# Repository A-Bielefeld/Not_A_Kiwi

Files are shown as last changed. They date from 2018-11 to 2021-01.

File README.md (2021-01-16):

# Not_A_Kiwi

This is an old begineer project, this electronics shouldn't be replicated or used for may reasons. It stands here as an archive to remind myself of how my very first project turned out!

<p align="center">
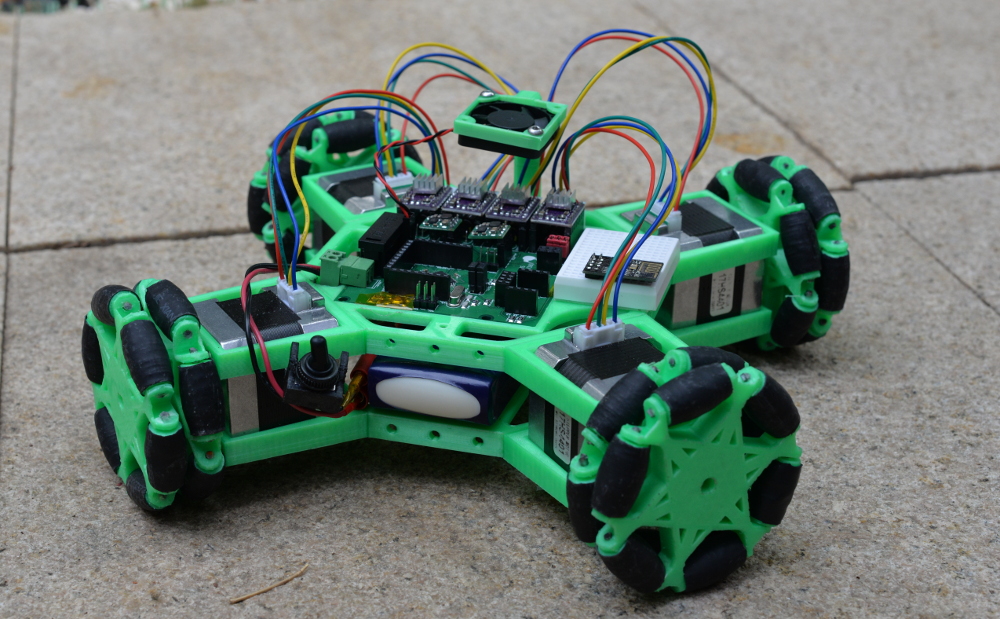
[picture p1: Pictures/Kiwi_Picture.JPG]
kiwi_robot

</p>

Not A Kiwi is an Open-Source, fully 3D printed modular robot controlled by a custom PCB. Its aims are to be an educational platform for engineering students and an entry in the 2019 Coupe de France de Robotique for the Robotics Assocations of Télécom Physique Strasbourg as a secondary robot.

This robot is meant for anyone seeking to have a fun and looking for an open robotics plateform to learn and expand on. The only tool needed to build one is a 3D printer, as the PCB can be bought online or provided by me (soldered or not).

## Features
- Based on a standard ATMega32, the board is arduino compatible (tested).
- Many headers and an integrated breadboard to test out new ideas and add sensors.
- Very easy to print, no complex parts.
- Modular 3D printed structure makes it easy to add any kind of sensor or effector.
- ESP01 socket (UART or I2C communication with the AVR) for IoT applications.

## Hardware
The hardware is the most developped part of this project as the code is still being written.

### BOM
- 4 Nema17 stepper motors (38mm)
- 4 DRV8825 stepper motor driver carriers (or A4988-Pinout-Compatible)
- 5V Pololu Regulator (D24V5F5, but I intend to replace them with a simpler/cheaper solution)
- 3.3V Pololu regulator (D24V5F3)
- ESP01 (not required)
- 12V LiPo battery (but any 12V to 36V battery will work fine)
- Not A Kiwi Board (Detailed below)
- Small Breadboard
- 30mm 0.15A fan
- 3D printed structure

#### Not A Kiwi Board

<p align="center">
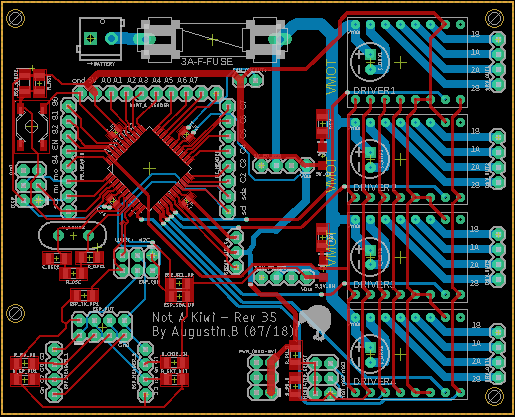
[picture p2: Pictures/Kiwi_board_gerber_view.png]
PCB_gerber_view

</p>

The board is a simple Atmega32 based board that includes 4 stepper motor driver carriers sockets as well as support for an ESP01 chip, communicating over either UART or I2C depending on a choice of jumpers. The BOM is rather small, as the board is meant to be programmed through ICSP. It is easily possible to send the BOM and Gerber files to a PCB production service to obtain one, although I can also provide fully soldered and tested ones for a fee (Europe only).

#### PCB BOM
The board uses a majority of SMD components, all 1206 except the AVR smoothing capacitor and a zener diode.

Most of these components can be soldered by hand, although it is advised to use solder paste and a reflow oven (a simple and inexpensive toaster oven is enough for this purpose).

Full BOM files will be provided in the repository, in a format compatible with most PCB manufacturers. 
An article explaining the choices behind the parts, and possible alternatives will be available on the wiki.

#### 3D printed structure

  The robot uses a simple 3D printed structure composed of 12 parts, it takes approximately 12 hours to print, not counting in the 3D printed omniwheels, but it would be much better to use bought ones, albeit more expensive (3D printed wheels have a negligeable cost, but perform more poorly, several design will be tested and offered here).
  
  The CAD files provided are Fusion 360 parametric files and therefore should also be compatible with Autodesk Inventor and SolidWorks (tested). If you just wish to print the robot, .STL files are also provided. The Kit also uses M3 screws and nuts, it is very quick and easy to assemble (less than an hour).
  
  <p align="center">
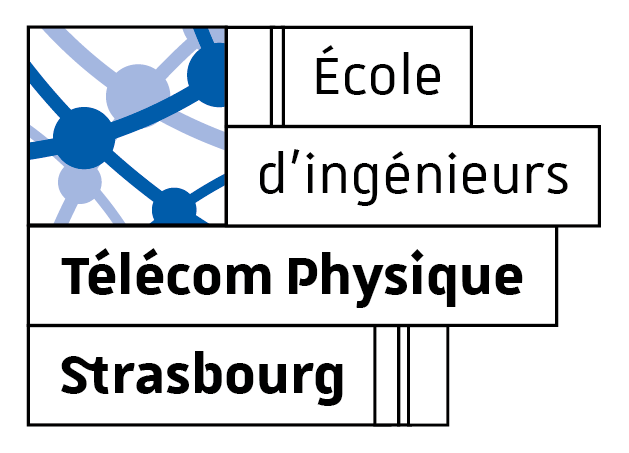
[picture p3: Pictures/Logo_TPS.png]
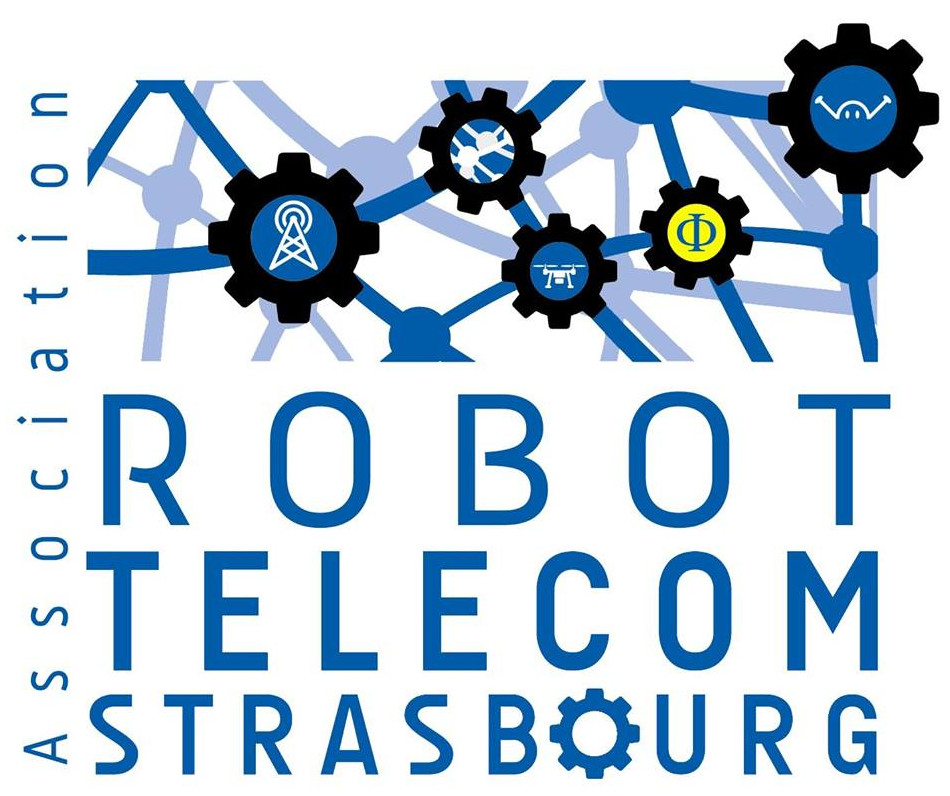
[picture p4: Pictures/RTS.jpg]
</p>

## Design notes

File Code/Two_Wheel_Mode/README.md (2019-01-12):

# Two wheeled driving mode

<p align="center">
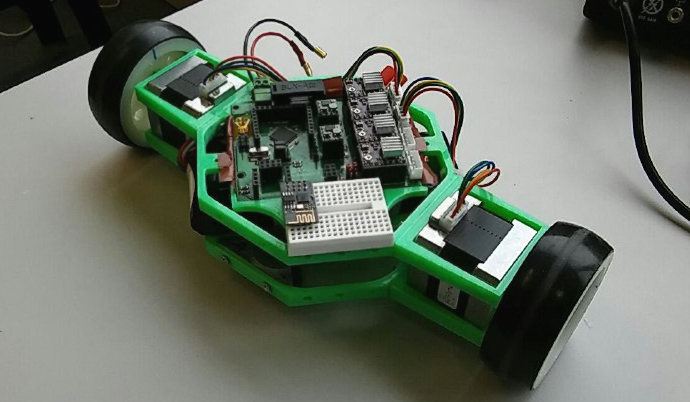
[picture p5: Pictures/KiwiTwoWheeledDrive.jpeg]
kiwi_robot in two wheeled mode

</p>

You can alter the structure by removing two motors bays and adding wheels and rollers on the bottom you can use this plateform in a simpler driving mode.
Polar movement code is provided here, for now it's a simple implementation providing rotational, and linear moves, along with two simple planning functions.

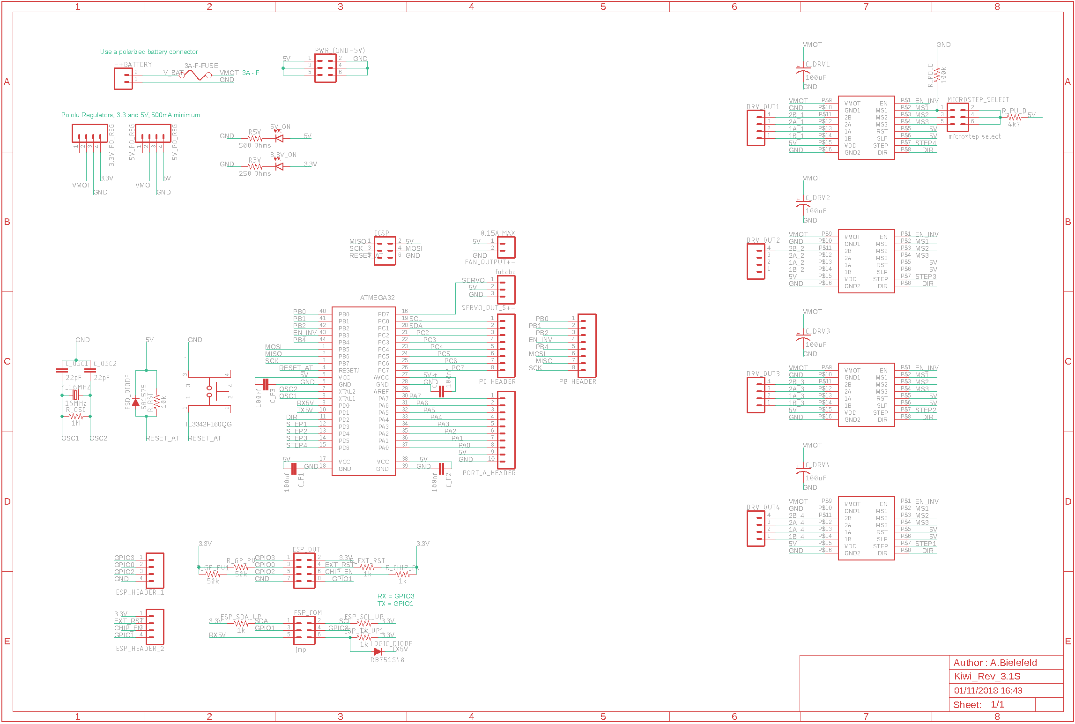
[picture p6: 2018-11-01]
Kiwi_Board/NAK_Board_Schematic_R3.1S.png

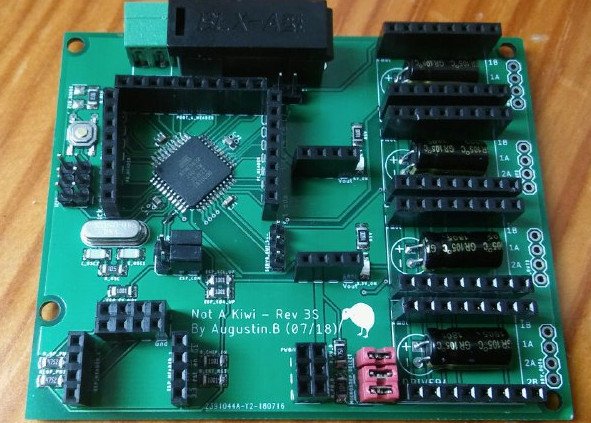
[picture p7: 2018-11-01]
Pictures/Kiwi_board_image.JPG

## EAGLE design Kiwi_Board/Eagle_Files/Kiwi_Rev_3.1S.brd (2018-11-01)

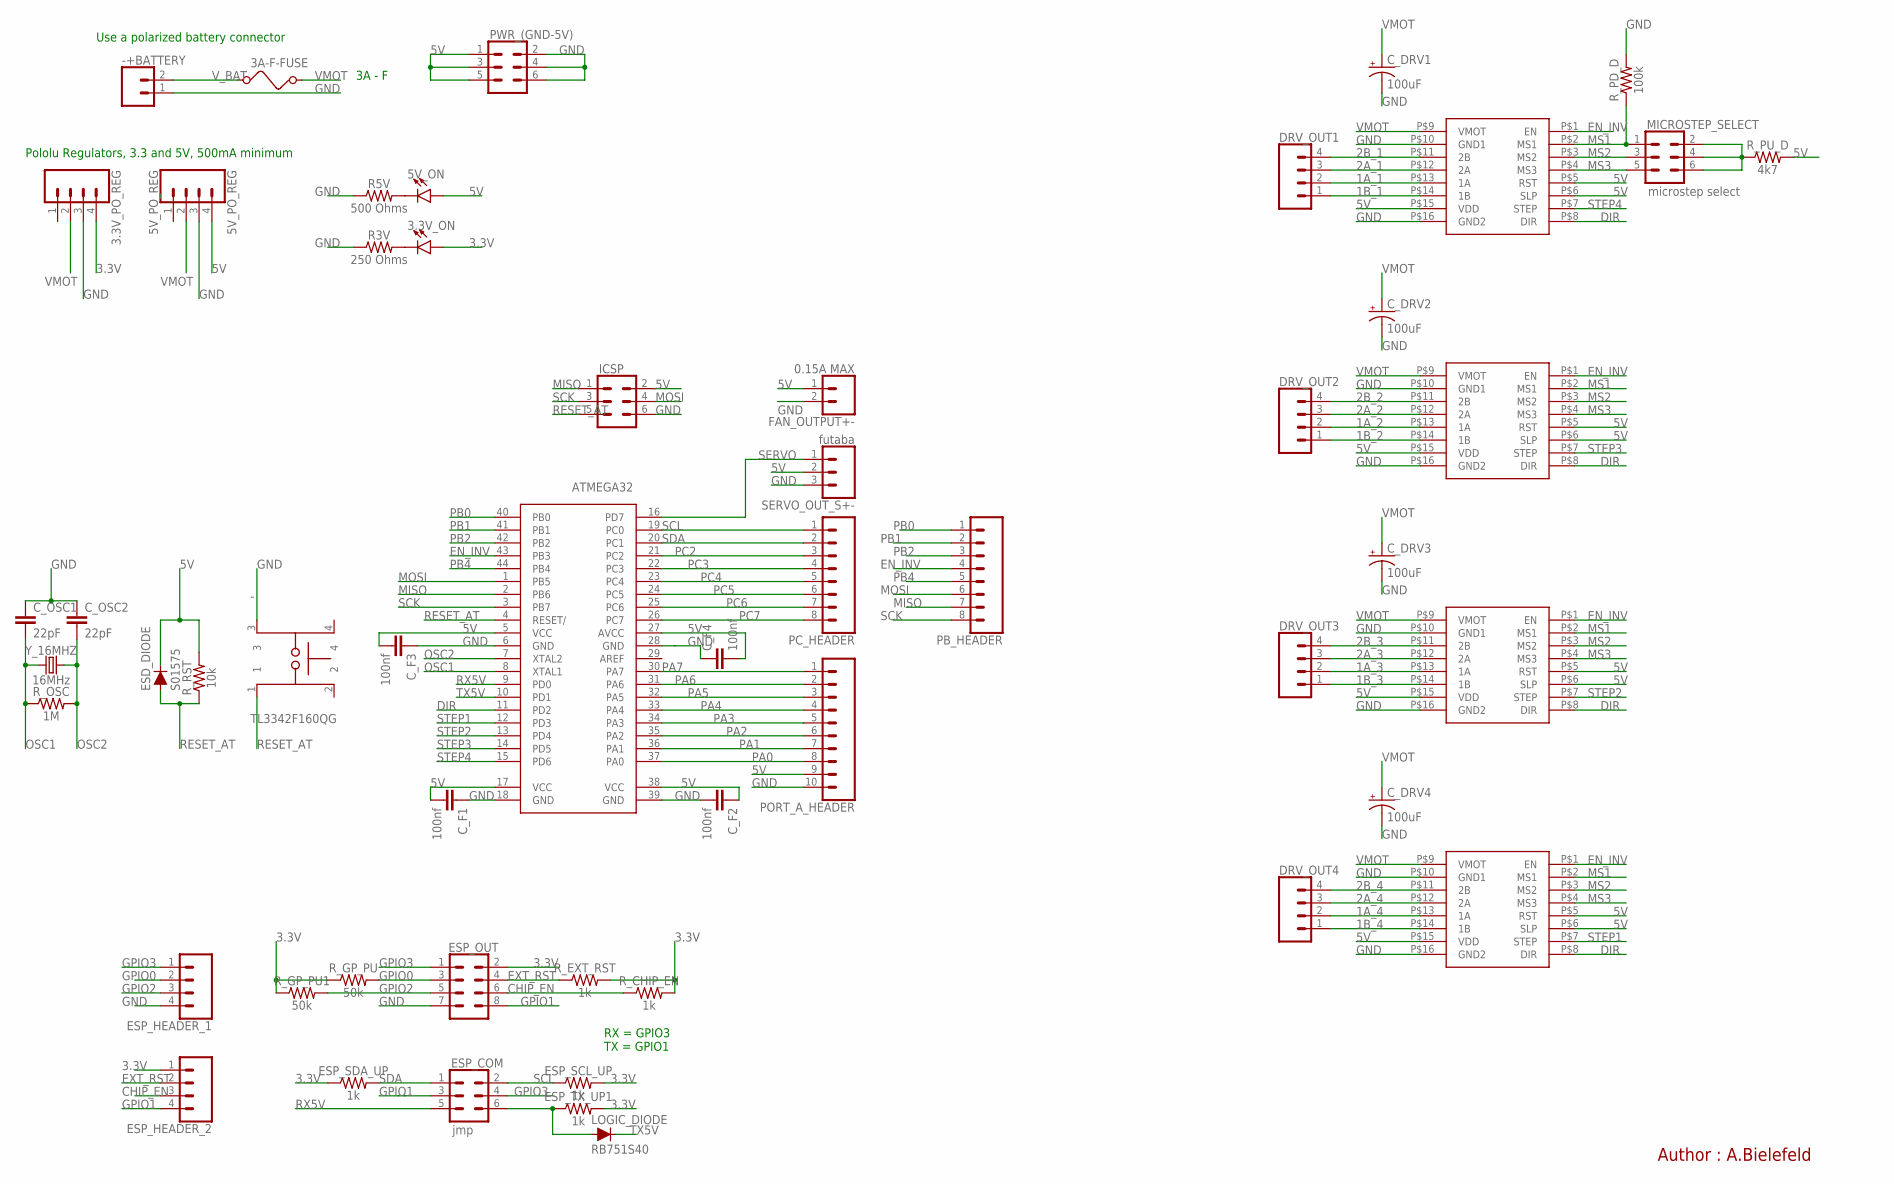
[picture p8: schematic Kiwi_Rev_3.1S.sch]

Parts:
3.3V_ON, 5V_ON: LED1206; LED-1206
3.3V_PO_REG: CONN_04; 1X04
3A-F-FUSE: FUSE
5V_PO_REG: 5V_PO_REG; 1X04
-: TL3342F160QG; SW_TL3342F160QG
-+BATTERY: CONN_023.5MM; SCREWTERMINAL-3.5MM-2
ATMEGA32: ATMEGA32; QFP80P1200X1200X120-44N
C_DRV1, C_DRV2, C_DRV3, C_DRV4: 100uF; CPOL-RADIAL-2.5MM-6.5MM
C_F1, C_F2, C_F3, C_F4: 100nf; 0603
C_OSC1, C_OSC2: 22pF; 1206
DRIVER1, DRIVER2, DRIVER3, DRIVER4: POLOLU_A4988; POLOLU_CARRIER
DRV_OUT1, DRV_OUT2, DRV_OUT3, DRV_OUT4: CONN_04; 1X04
ESD_DIODE: S01575; 1206
ESP_COM: jmp; 2X3
ESP_HEADER_1, ESP_HEADER_2: CONN_04; 1X04
ESP_OUT: CONN_04X2; 2X4
ESP_SCL_UP: 1k; 1206
ESP_SDA_UP: 1k; 1206
ESP_TX_UP1: 1k; 1206
FAN_OUTPUT+-: 0.15A MAX; 1X02
ICSP: CONN_03X22X3_SILK_MALE_PTH; 2X3
LOGIC_DIODE: RB751S40; SOD523
MICROSTEP_SELECT: microstep select; 2X3
PB_HEADER: CONN_08"; 1X08
PC_HEADER: CONN_08"; 1X08
PORT_A_HEADER: CONN_10"; 1X10
PWR_(GND-5V): CONN_03X22X3_SILK_MALE_PTH; 2X3
R3V: 250 Ohms; 1206
R5V: 500 Ohms; 1206
R_CHIP_EN: 1k; 1206
R_EXT_RST: 1k; 1206
R_GP_PU, R_GP_PU1: 50k; 1206
R_OSC: 1M; 1206
R_PD_D: 100k; 1206
R_PU_D: 4k7; 1206
R_RST: 10k; 1206
SERVO_OUT_S+-: futaba; 1X03
Y_16MHZ: 16MHz; HC49US

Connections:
1A_1: DRIVER1.P$13 (1A), DRV_OUT1.2
1A_2: DRIVER2.P$13 (1A), DRV_OUT2.2
1A_3: DRIVER3.P$13 (1A), DRV_OUT3.2
1A_4: DRIVER4.P$13 (1A), DRV_OUT4.2
1B_1: DRIVER1.P$14 (1B), DRV_OUT1.1
1B_2: DRIVER2.P$14 (1B), DRV_OUT2.1
1B_3: DRIVER3.P$14 (1B), DRV_OUT3.1
1B_4: DRIVER4.P$14 (1B), DRV_OUT4.1
2A_1: DRIVER1.P$12 (2A), DRV_OUT1.3
2A_2: DRIVER2.P$12 (2A), DRV_OUT2.3
2A_3: DRIVER3.P$12 (2A), DRV_OUT3.3
2A_4: DRIVER4.P$12 (2A), DRV_OUT4.3
2B_1: DRIVER1.P$11 (2B), DRV_OUT1.4
2B_2: DRIVER2.P$11 (2B), DRV_OUT2.4
2B_3: DRIVER3.P$11 (2B), DRV_OUT3.4
2B_4: DRIVER4.P$11 (2B), DRV_OUT4.4
3.3V: 3.3V_ON.A, 3.3V_PO_REG.4, ESP_HEADER_2.1, ESP_OUT.2, ESP_SCL_UP.2, ESP_SDA_UP.1, ESP_TX_UP1.2, R_CHIP_EN.2, R_EXT_RST.2, R_GP_PU.1, R_GP_PU1.1
5V: 5V_ON.A, 5V_PO_REG.4, ATMEGA32.5 (VCC), ATMEGA32.17 (VCC), ATMEGA32.27 (AVCC), ATMEGA32.38 (VCC), C_F1.2, C_F2.1, C_F3.2, C_F4.2, DRIVER1.P$5 (RST), DRIVER1.P$6 (SLP), DRIVER1.P$15 (VDD), DRIVER2.P$5 (RST), DRIVER2.P$6 (SLP), DRIVER2.P$15 (VDD), DRIVER3.P$5 (RST), DRIVER3.P$6 (SLP), DRIVER3.P$15 (VDD), DRIVER4.P$5 (RST), DRIVER4.P$6 (SLP), DRIVER4.P$15 (VDD), ESD_DIODE.2 (C), FAN_OUTPUT+-.1, ICSP.2, PORT_A_HEADER.9, PWR_(GND-5V).1, PWR_(GND-5V).3, PWR_(GND-5V).5, R_PU_D.2, R_RST.2, SERVO_OUT_S+-.2
CHIP_EN: ESP_HEADER_2.3, ESP_OUT.6, R_CHIP_EN.1
DIR: ATMEGA32.11 (PD2), DRIVER1.P$8 (DIR), DRIVER2.P$8 (DIR), DRIVER3.P$8 (DIR), DRIVER4.P$8 (DIR)
EN_INV: ATMEGA32.43 (PB3), DRIVER1.P$1 (EN), DRIVER2.P$1 (EN), DRIVER3.P$1 (EN), DRIVER4.P$1 (EN), PB_HEADER.4
EXT_RST: ESP_HEADER_2.2, ESP_OUT.4, R_EXT_RST.1
GND: 3.3V_PO_REG.3, 5V_PO_REG.3, -.3, -+BATTERY.1, ATMEGA32.6 (GND), ATMEGA32.18 (GND), ATMEGA32.28 (GND), ATMEGA32.39 (GND), C_DRV1.2 (-), C_DRV2.2 (-), C_DRV3.2 (-), C_DRV4.2 (-), C_F1.1, C_F2.2, C_F3.1, C_F4.1, C_OSC1.1, C_OSC2.1, DRIVER1.P$10 (GND1), DRIVER1.P$16 (GND2), DRIVER2.P$10 (GND1), DRIVER2.P$16 (GND2), DRIVER3.P$10 (GND1), DRIVER3.P$16 (GND2), DRIVER4.P$10 (GND1), DRIVER4.P$16 (GND2), ESP_HEADER_1.4, ESP_OUT.7, FAN_OUTPUT+-.2, ICSP.6, PORT_A_HEADER.10, PWR_(GND-5V).2, PWR_(GND-5V).4, PWR_(GND-5V).6, R3V.1, R5V.1, R_PD_D.2, SERVO_OUT_S+-.3
GPIO0: ESP_HEADER_1.2, ESP_OUT.3, R_GP_PU.2
GPIO1: ESP_COM.3, ESP_HEADER_2.4, ESP_OUT.8
GPIO2: ESP_HEADER_1.3, ESP_OUT.5, R_GP_PU1.2
GPIO3: ESP_COM.4, ESP_HEADER_1.1, ESP_OUT.1
MISO: ATMEGA32.2 (PB6), ICSP.1, PB_HEADER.7
MOSI: ATMEGA32.1 (PB5), ICSP.4, PB_HEADER.6
MS1: DRIVER1.P$2 (MS1), DRIVER2.P$2 (MS1), DRIVER3.P$2 (MS1), DRIVER4.P$2 (MS1), MICROSTEP_SELECT.1, R_PD_D.1
MS2: DRIVER1.P$3 (MS2), DRIVER2.P$3 (MS2), DRIVER3.P$3 (MS2), DRIVER4.P$3 (MS2), MICROSTEP_SELECT.3
MS3: DRIVER1.P$4 (MS3), DRIVER2.P$4 (MS3), DRIVER3.P$4 (MS3), DRIVER4.P$4 (MS3), MICROSTEP_SELECT.5
unnamed: 3.3V_ON.C, R3V.2
unnamed: 5V_ON.C, R5V.2
unnamed: ESP_COM.6, ESP_TX_UP1.1, LOGIC_DIODE.A
NET_PU1: MICROSTEP_SELECT.2, MICROSTEP_SELECT.4, MICROSTEP_SELECT.6, R_PU_D.1
OSC1: ATMEGA32.8 (XTAL1), C_OSC1.2, R_OSC.1, Y_16MHZ.1
OSC2: ATMEGA32.7 (XTAL2), C_OSC2.2, R_OSC.2, Y_16MHZ.2
PA0: ATMEGA32.37 (PA0), PORT_A_HEADER.8
PA1: ATMEGA32.36 (PA1), PORT_A_HEADER.7
PA2: ATMEGA32.35 (PA2), PORT_A_HEADER.6
PA3: ATMEGA32.34 (PA3), PORT_A_HEADER.5
PA4: ATMEGA32.33 (PA4), PORT_A_HEADER.4
PA5: ATMEGA32.32 (PA5), PORT_A_HEADER.3
PA6: ATMEGA32.31 (PA6), PORT_A_HEADER.2
PA7: ATMEGA32.30 (PA7), PORT_A_HEADER.1
PB0: ATMEGA32.40 (PB0), PB_HEADER.1
PB1: ATMEGA32.41 (PB1), PB_HEADER.2
PB2: ATMEGA32.42 (PB2), PB_HEADER.3
PB4: ATMEGA32.44 (PB4), PB_HEADER.5
PC2: ATMEGA32.21 (PC2), PC_HEADER.3
PC3: ATMEGA32.22 (PC3), PC_HEADER.4
PC4: ATMEGA32.23 (PC4), PC_HEADER.5
PC5: ATMEGA32.24 (PC5), PC_HEADER.6
PC6: ATMEGA32.25 (PC6), PC_HEADER.7
PC7: ATMEGA32.26 (PC7), PC_HEADER.8
RESET_AT: -.1, ATMEGA32.4 (RESET/), ESD_DIODE.1 (A), ICSP.5, R_RST.1
RX5V: ATMEGA32.9 (PD0), ESP_COM.5
SCK: ATMEGA32.3 (PB7), ICSP.3, PB_HEADER.8
SCL: ATMEGA32.19 (PC0), ESP_COM.2, ESP_SCL_UP.1, PC_HEADER.1
SDA: ATMEGA32.20 (PC1), ESP_COM.1, ESP_SDA_UP.2, PC_HEADER.2
SERVO: ATMEGA32.16 (PD7), SERVO_OUT_S+-.1
STEP1: ATMEGA32.12 (PD3), DRIVER4.P$7 (STEP)
STEP2: ATMEGA32.13 (PD4), DRIVER3.P$7 (STEP)
STEP3: ATMEGA32.14 (PD5), DRIVER2.P$7 (STEP)
STEP4: ATMEGA32.15 (PD6), DRIVER1.P$7 (STEP)
TX5V: ATMEGA32.10 (PD1), LOGIC_DIODE.C
VMOT: 3.3V_PO_REG.2, 3A-F-FUSE.2, 5V_PO_REG.2, C_DRV1.1 (+), C_DRV2.1 (+), C_DRV3.1 (+), C_DRV4.1 (+), DRIVER1.P$9 (VMOT), DRIVER2.P$9 (VMOT), DRIVER3.P$9 (VMOT), DRIVER4.P$9 (VMOT)
V_BAT: 3A-F-FUSE.1, -+BATTERY.2

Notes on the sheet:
Use a polarized battery connector
3A - F
RX = GPIO3 TX = GPIO1
Pololu Regulators, 3.3 and 5V, 500mA minimum
Author : A.Bielefeld

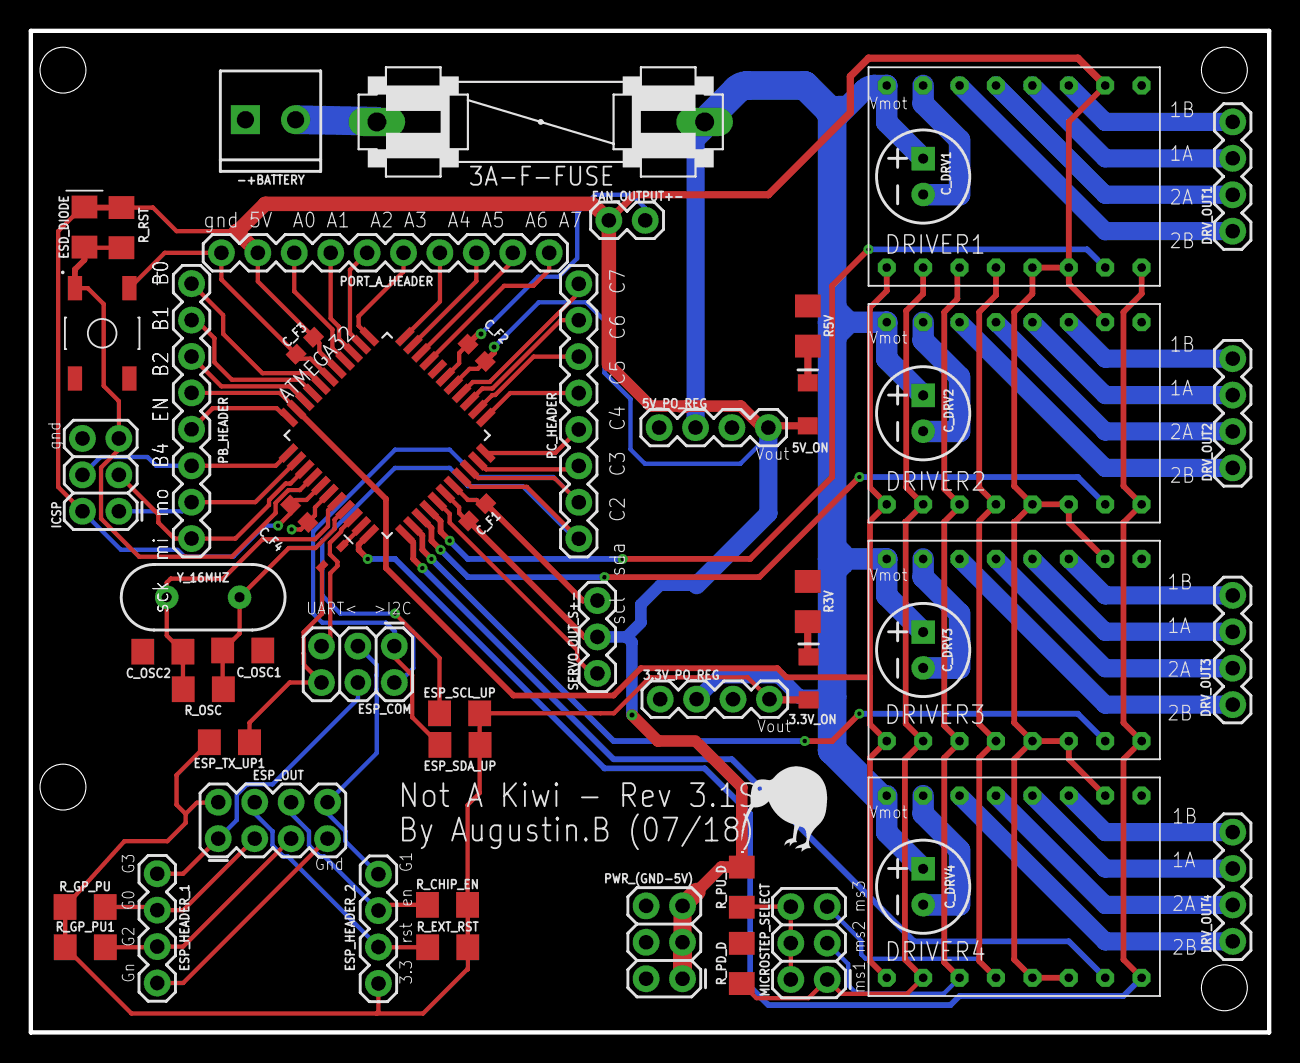
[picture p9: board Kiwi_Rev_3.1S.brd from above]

Board: 2 copper layers, 86.4 x 69.8 mm, 54 parts (0 on the bottom side), 69 nets.

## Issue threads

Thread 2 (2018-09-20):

Smol code nags

Xasin, 2018-09-20:
I said I'd make a few issues regarding your code.
Let's start with an easy one to get a bit of the workflow down :>

I noticed a few things that could be fixed:

- [x] An `#endif` needs to be here:
  https://github.com/A-Bielefeld/Not_A_Kiwi/blob/4d524ffcdbf3b5e978804fbfd2a695a749447558/libraries/Simple_Step/Simple_Step.h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
- [x] `Stepper` should be capitalized:
  https://github.com/A-Bielefeld/Not_A_Kiwi/blob/4d524ffcdbf3b5e978804fbfd2a695a749447558/libraries/Simple_Step/Simple_Step.h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
- [x] These can be marked as `const`. Not necessary, but it helps the compiler out a bit, and makes sense: https://github.com/A-Bielefeld/Not_A_Kiwi/blob/4d524ffcdbf3b5e978804fbfd2a695a749447558/libraries/Simple_Step/Simple_Step.h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
- [ ] I would also add a variable to save the current speed of the motor, but that depends on your implementation.
- [ ] Maybe also use a namespace to encapsulate all the movement code logically.

Closed 2018-09-24.

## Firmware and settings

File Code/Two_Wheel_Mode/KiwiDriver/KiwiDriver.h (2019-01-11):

/*
 * KiwiDriver.h
 *
 *  Created on: Jan 6, 2019
 *      Author: yyunko
 */

#ifndef KIWIDRIVER_H_
#define KIWIDRIVER_H_

#include"../Stepper/Stepper.h"
#include"../Timer1/Timer1.h"

#define STEPS_PER_TURN 3200.0
#define WHEEL_RADIUS 3.725 //units cm
#define DIST_WHEEL_TO_WHEEL 25.0 //unis cm

#define M_PI 3.14159265358979323846 //Pi
#define DEG_TO_RAD 0.01745329238

#define TIMER_PRESC TIMER1_PRESC_1
#define TIMER_PRESC_VALUE 1
#define CLOCK_SPEED (16000000/TIMER_PRESC_VALUE)

#define MAX_SPEED_LIN 120 //units cm/s
#define MIN_SPEED_LIN 5 //units cm/s
#define MAX_SPEED_ROT 360 //units degrees/s
#define MIN_SPEED_ROT 10 //units degrees/s*/

#define PORT_STEP_R PORTD
#define PORT_DIR_R PORTD
#define PORT_EN_R PORTB
#define PIN_STEP_R 5
#define PIN_DIR_R 2
#define PIN_EN_R 3

#define PORT_STEP_L PORTD
#define PORT_DIR_L PORTD
#define PORT_EN_L PORTB
#define PIN_STEP_L 6
#define PIN_DIR_L 2
#define PIN_EN_L 3

//Usefull constants
const float wheelCircumference = 2*M_PI*WHEEL_RADIUS;
const float stepsPerCm = STEPS_PER_TURN/wheelCircumference;
const float stepsPerDegree = DEG_TO_RAD*(DIST_WHEEL_TO_WHEEL/2)*stepsPerCm;

const float ISR_period = 1/TIMER_PRESC_VALUE;

//Function that initializes timer registers
void configureISR();

//Toggles the drivers on and off
void toggle(uint8_t state);

//Issues a relative linear move command, with distance in cm, and speed in cm/s
void linearMove(float distance, float speed);

//Issues a relative rotation move command, with angle in degrees and speed in degrees/s
void rotateMove(float angle, float speed);

//Return true if the current move is done
bool moveDone();

//Blocking function, waits until kiwiReady() returns one
void waitOnMove();


#endif /* KIWIDRIVER_H_ */

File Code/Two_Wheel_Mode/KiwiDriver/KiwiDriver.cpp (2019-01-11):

/*
 * KiwiDriver.cpp
 *
 *  Created on: Jan 6, 2019
 *      Author: yyunko
 */

#include<avr/io.h>
#include<avr/interrupt.h>
#include"KiwiDriver.h"
#include"../Stepper/Stepper.h"

//Creates the robot's driver motors
Stepper motorRight(&PORT_STEP_R, &PORT_DIR_R, &PORT_EN_R, PIN_STEP_R, PIN_DIR_R, PIN_EN_R, STEPS_PER_TURN);
Stepper motorLeft(&PORT_STEP_L, &PORT_DIR_L, &PORT_EN_L, PIN_STEP_L, PIN_DIR_L, PIN_EN_L, STEPS_PER_TURN);

void configureISR(){
	Timer1::set_mode(TIMER1_MODE_CTC);
	Timer1::set_prescaler(TIMER1_PRESC_1);
	sei();
}

void toggle(uint8_t state){
	motorRight.toggle(state);
	motorLeft.toggle(state);
}

void linearMove(float distance, float speed){
	if (speed<MIN_SPEED_LIN) {speed = MIN_SPEED_LIN;}
	else if (speed>MAX_SPEED_LIN) {speed = MAX_SPEED_LIN;}

	motorRight.move((int32_t)(-distance*stepsPerCm));
	motorLeft.move((int32_t)(distance*stepsPerCm));

	speed = (speed*stepsPerCm); //Converting to steps/s

	cli();
	Timer1::set_OCR1A((uint16_t)(CLOCK_SPEED/speed));
	sei();
}

void rotateMove(float angle, float speed){
	if (speed<MIN_SPEED_ROT) {speed = MIN_SPEED_ROT;}
	else if (speed>MAX_SPEED_ROT) {speed = MAX_SPEED_ROT;}

	motorRight.move((int32_t)(angle*stepsPerDegree));
	motorLeft.move((int32_t)(angle*stepsPerDegree));

	speed = (speed*stepsPerDegree); //Converting to steps/s

	cli();
	Timer1::set_OCR1A((uint16_t)(CLOCK_SPEED/speed));
	sei();
}

bool moveDone(){
	if (motorRight.done() && motorLeft.done()){
		return true;
	}
	else{
		return false;
	}
}

void waitOnMove(){
	while (!moveDone()){
	}
}

ISR (TIMER1_COMPA_vect){
	if (!motorLeft.done()){
		motorLeft.step();
	}
	if (!motorRight.done()){
		motorRight.step();
	}
}

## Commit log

2018-11-01 Added all the CAM and CAD files for the NAK Board
    [Kiwi_Rev_3.1S.brd, Kiwi_Rev_3.1S.sch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]
2019-01-11 added new image for Two Wheeled Drive option
2019-01-11 Added driver code for two wheeled driving mode
    Simple polar movements without accelerations are supported, rotate, linear moves, and simple movement logic and laying out work for an acceleration class, as well as future use of the bresenham algor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

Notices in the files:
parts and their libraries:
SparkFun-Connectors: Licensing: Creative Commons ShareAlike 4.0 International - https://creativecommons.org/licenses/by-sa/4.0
